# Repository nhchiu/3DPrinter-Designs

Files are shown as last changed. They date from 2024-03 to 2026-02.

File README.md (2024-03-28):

# 3D Printer Designs

Collection of miscellaneous parts and upgrades for 3D printers.

## Support

Making, testing, and sharing these designs take a lot of time and effort.

If you would like to support my work, the following platforms are available:




Thank you!

## License



Unless being specifically noted, the work in the repository is licensed under [CC BY-NC-SA 4.0](http://creativecommons.org/licenses/by-nc-sa/4.0/?ref=chooser-v1)

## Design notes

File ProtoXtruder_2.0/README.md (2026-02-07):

# ProtoXtruder 2.0

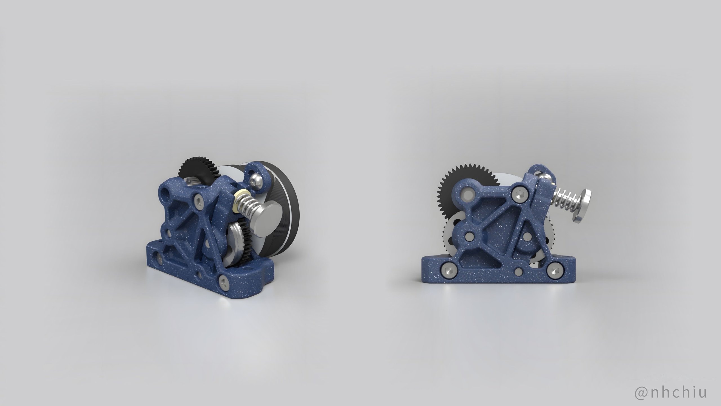
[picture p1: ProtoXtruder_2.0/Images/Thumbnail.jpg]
Thumbnail


This is the successor to [ProtoXtruder](https://www.printables.com/model/436425-protoxtruder).
With the new gears from the [HGX 2.0 Extruder](https://s.click.aliexpress.com/e/_Dmy9Crl) **(affiliate link)**,
the design becomes thinner and lighter while preserving the benefits of the larger gears.

Although it is named ProtoXtruder **2.0**, it's not a direct upgrade from the previous design.
There isn't much you can reuse in the BOM.

Refer to the drawing below for dimensions and compatibility with your printer.
The mounting holes are compatible with the [Sherpa Mini Extruder](https://github.com/Annex-Engineering/Sherpa_Mini-Extruder).

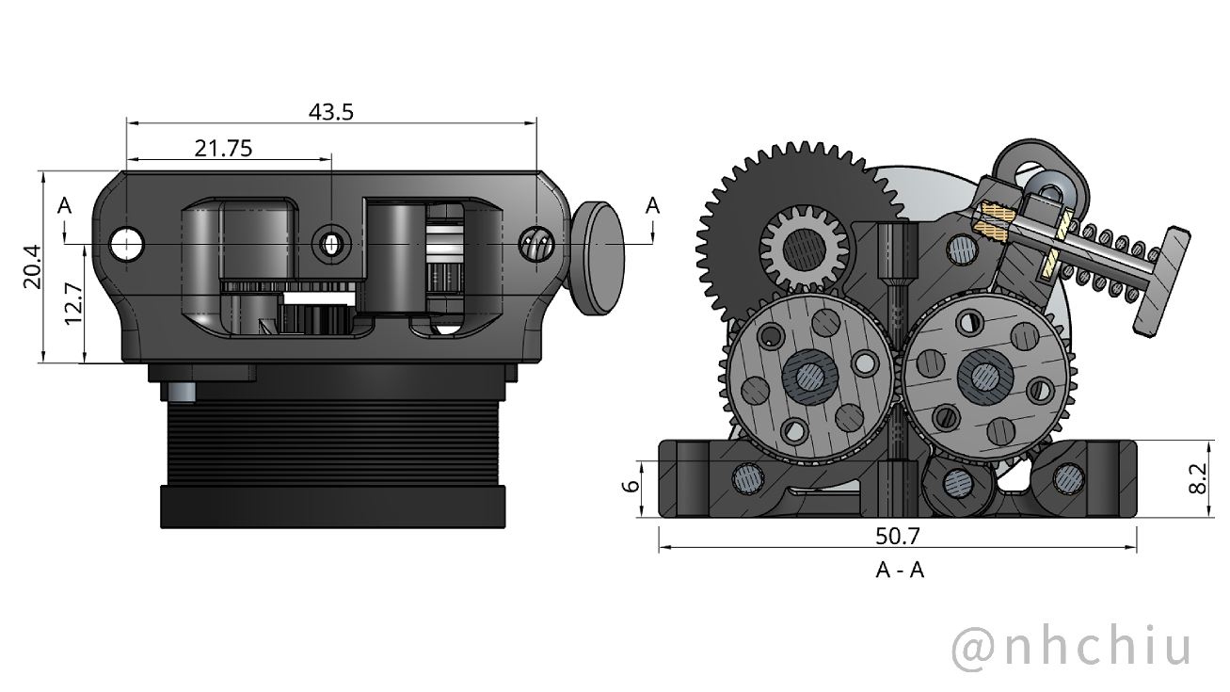
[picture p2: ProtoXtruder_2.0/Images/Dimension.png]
Dimension


If you'd like to support my work, the following platforms are available. Thank you!




> This page contains affiliate links. If you purchase products through these links, I may earn a small commission at no additional cost to you.
> This helps support the development and maintenance of my projects. Thank you for your support!

## Features

- High gear reduction ratios (44:10, 37:17).
- Large extrusion gears (18 mm diameter) providing a large filament contact area.
- Oblique/twirling hobbed teeth for improved filament grip and consistent flow.*
- Compact and lightweight. All printed parts can be produced in about one hour.
- Variants for different Bowden tube retainers.
- Low profile and low center of mass.
- Optional support for a toolhead filament sensor.

> [!NOTE]
> *: The effect of the oblique/twirling teeth still needs further testing.
>
> Below are pros and cons based on my experience and feedback regarding the [Vz-HextrudORT](https://github.com/VzBoT3D/Vz-HextrudORT):
>
> Pros:
>
> - It requires very little tension to provide a very good grip on the filament.
> - The inclined tooth profile causes less deviation in flow rate when it leaves tooth marks on the filament.
>
> Cons:
>
> - It introduces a twisting force on the filament under higher back pressure from the hotend.
>   This may cause issues when printing flexible materials or at high flow rates.
>
> I haven't observed issues with the HGX 2.0 gears so far, but your mileage may vary.

## Weight Comparison

This is a rough reference; the parts were not printed in identical materials or with identical print profiles.

The CNC Vz-HextrudORT I received is from early batches.
Later versions added more cutouts, so newer ones are likely lighter.

From left to right:

|  Extruder  | CNC<br />VzHextrudort | Sherpa mini | Hummingbird | ProtoXtruder | ProtoXtruder 2.0 | HGX 2.0 |
| :---: | :---: | :---: | :---: | :---: | :---: | :-----: |
| Weight (g) | 40.0 | 34.9 | 49.6 | 46.4 | 39.5 |  51.0 |

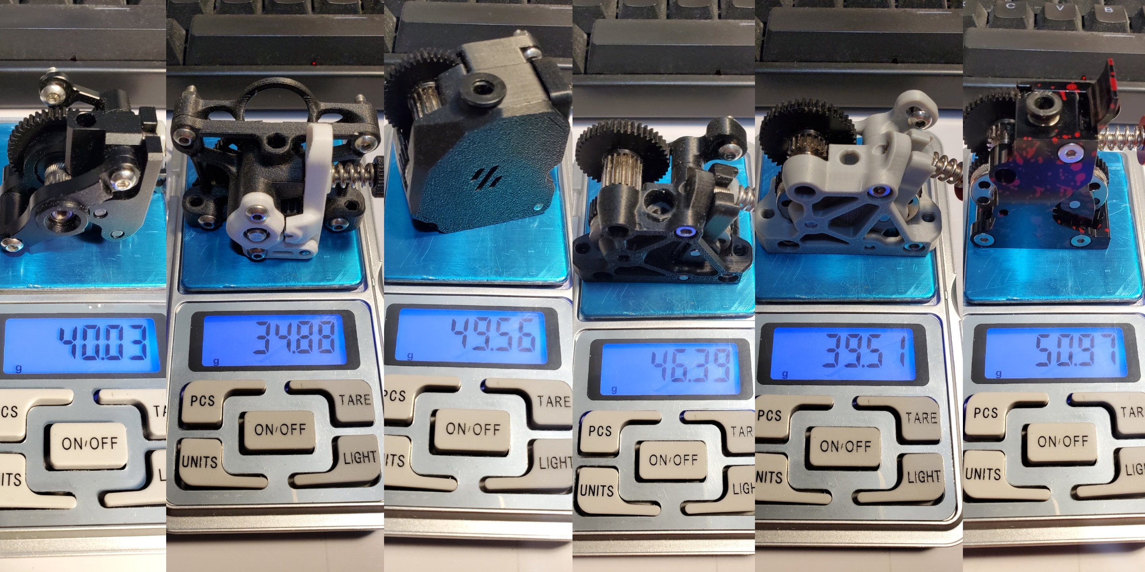
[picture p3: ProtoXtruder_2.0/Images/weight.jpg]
weight


## BOM

- Oblique Tooth HGX 2.0 Extruder Gear Kit ([this](https://s.click.aliexpress.com/e/_Dmy9Crl) or [this](https://s.click.aliexpress.com/e/_Dn3gb6n)) **(both are affiliate links)**. (I'm not certain what's included in the gear kit; I'll update this as I receive confirmation or feedback.)
  - MR63ZZ bearings × 6
  - 3 mm shaft (18 mm length) × 1 (16–18 mm may work)
  - 3 mm shaft (16 mm length) × 1 (14–16 mm may work)
  - Large extrusion gear (with oblique teeth) × 2
  - Reduction gear × 1
  - Thumb screw and tensioner spring
- Fasteners:
  - M3 × 8 mm BHCS × 1
  - M3 × 16 mm SHCS × 3
  - M3 × 20 mm SHCS × 1
  - Heat-set inserts (Voron size — M3 × D5 × H4) × 3
- NEMA14 36 mm round pancake motor with 10T gear (8T should be compatible)

## Print Settings

Use at least 3 perimeters and 40% infill. ABS or ASA recommended.

All STL files are oriented for printing; no supports required.

It will need *some* bridging.

## Assembly

1. Install M3 heat-set inserts.

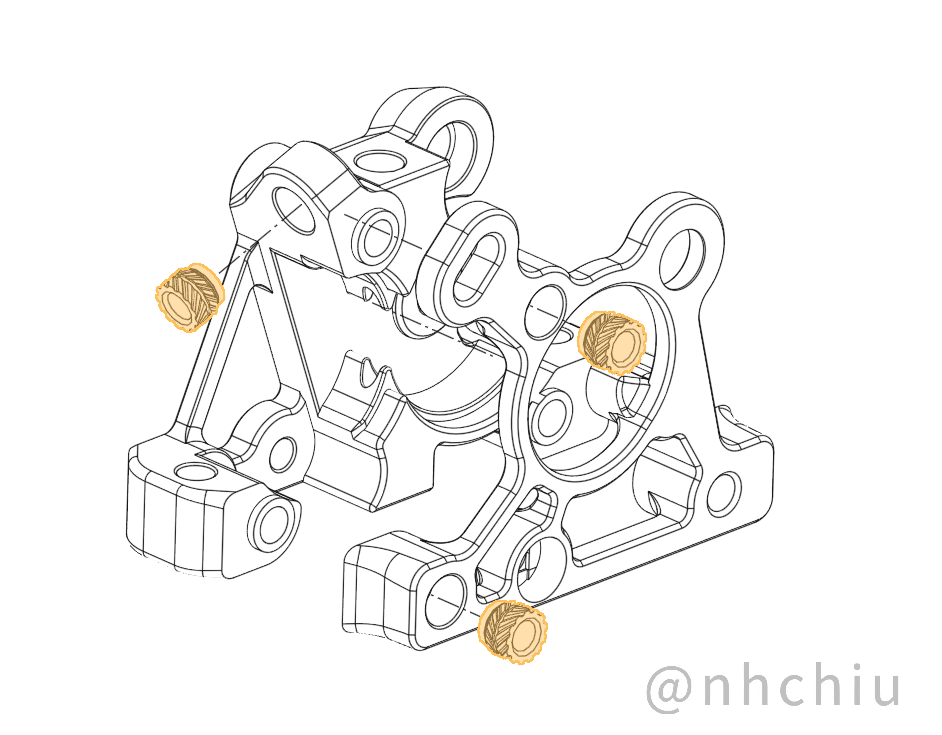
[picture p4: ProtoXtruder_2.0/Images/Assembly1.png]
Assembly1
   

2. Insert the MR63 bearings into the extrusion gears (two per gear).

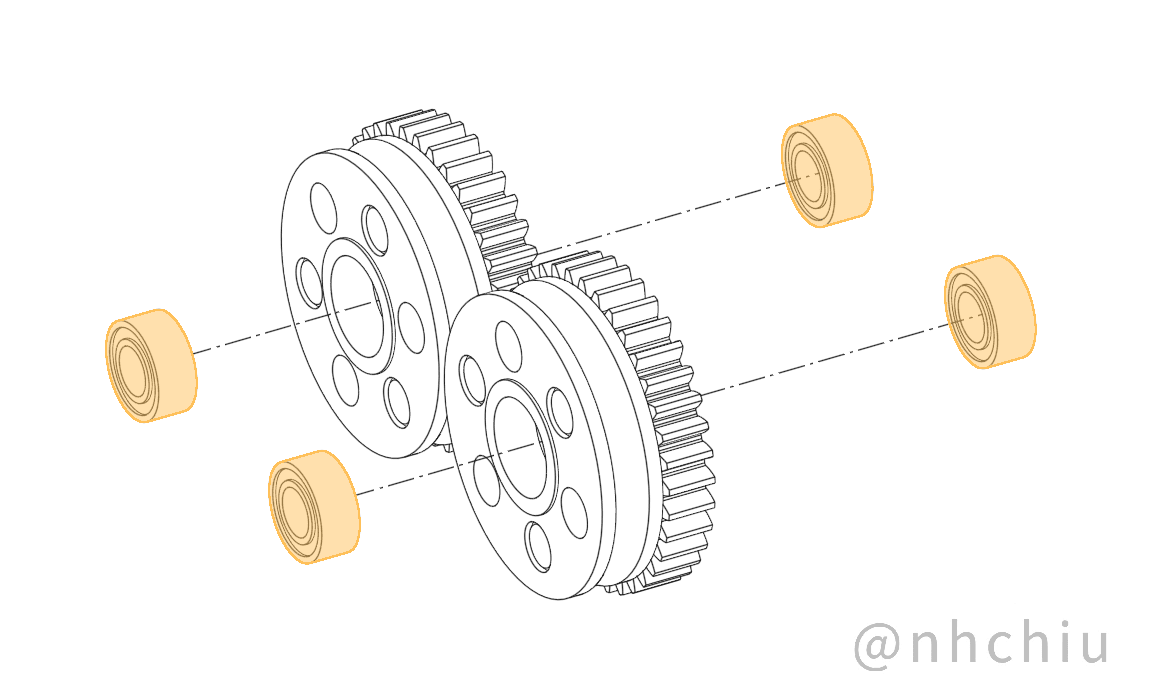
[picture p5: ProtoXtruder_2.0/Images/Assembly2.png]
Assembly2
   

3. Assemble the extruder using the fasteners.

   **Note: the M3 × 16 SHCS inserted from the motor side threads into plastic - do not overtighten.**
   **Tighten only until the screw head is flush with the printed part.**

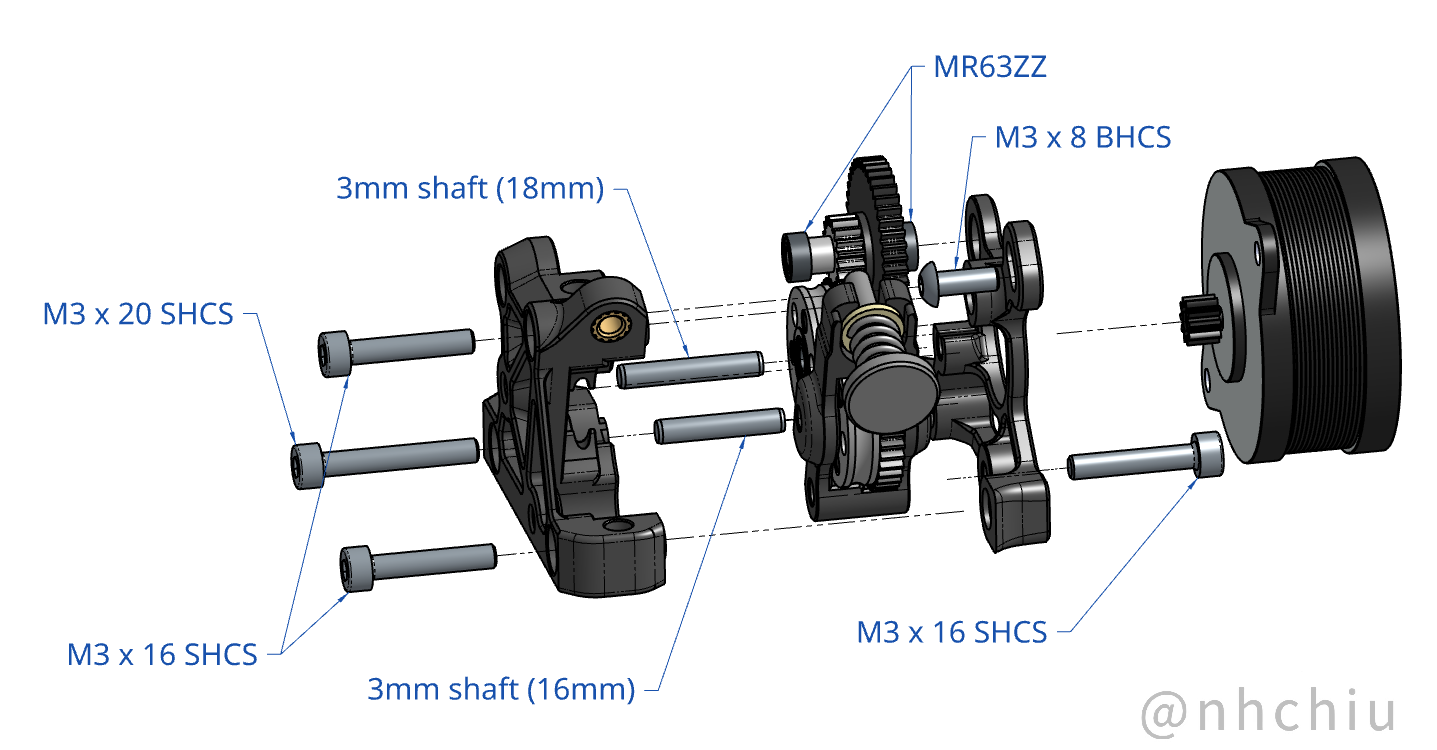
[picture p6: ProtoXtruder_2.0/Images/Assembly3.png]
Assembly3
   

4. (Optional) Add the Bowden tube retainer of your choice.

   **Remove the bottom half of the ECAS04 (the black plastic/rubber parts).**

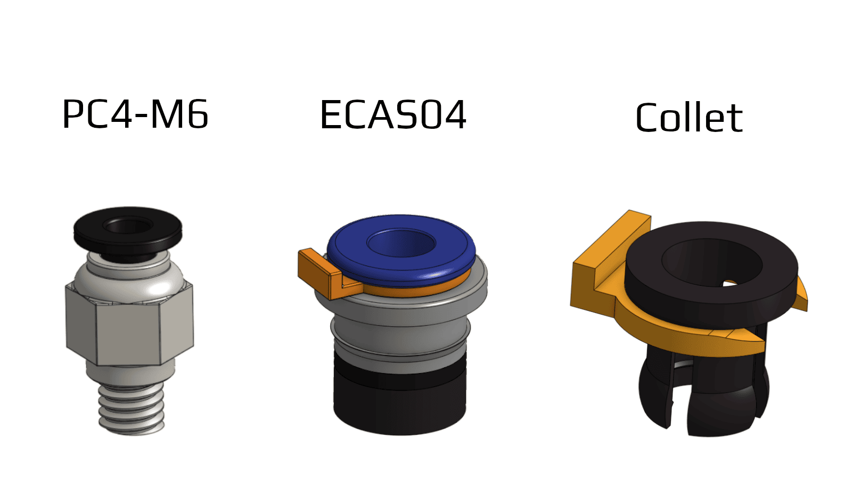
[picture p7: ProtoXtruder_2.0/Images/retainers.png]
retainers
   

## Toolhead Filament Sensor

Use in conjunction with this **Toolhead Filament Sensor for ProtoXtruder 2.0**

<iframe src="https://www.printables.com/embed/1589915" width="400" height="445" scrolling="no" frameborder="0"></iframe>

## Firmware Settings

For [Klipper firmware](https://www.klipper3d.org/):

```ini
[extruder]
rotation_distance: 53.494165  # Re-calibrate your own value
gear_ratio: 44:10, 37:17
```

**You might need to invert the `dir_pin` of the extruder.**

## Changelog

### 2026-02-08

- Add support for toolhead filament sensor

### 2024-04-19

- Update to match the pin length of the gear kit.

### 2024-03-28

- Initial release

## Special Thanks

Designing and testing an extruder takes a lot of time and many iterations.

Thanks to [Polymaker](https://polymaker.com/) for sponsoring the filament used to print many prototypes.

Also thanks to Haldis / HS3DPrinter for sending me an HGX 2.0 extruder so I could design with their new gears.
Their products are available on [their website](https://hs3dprinter.com/) and [AliExpress](https://s.click.aliexpress.com/e/_DchaZFt) **(affiliate link)**.

## Photo

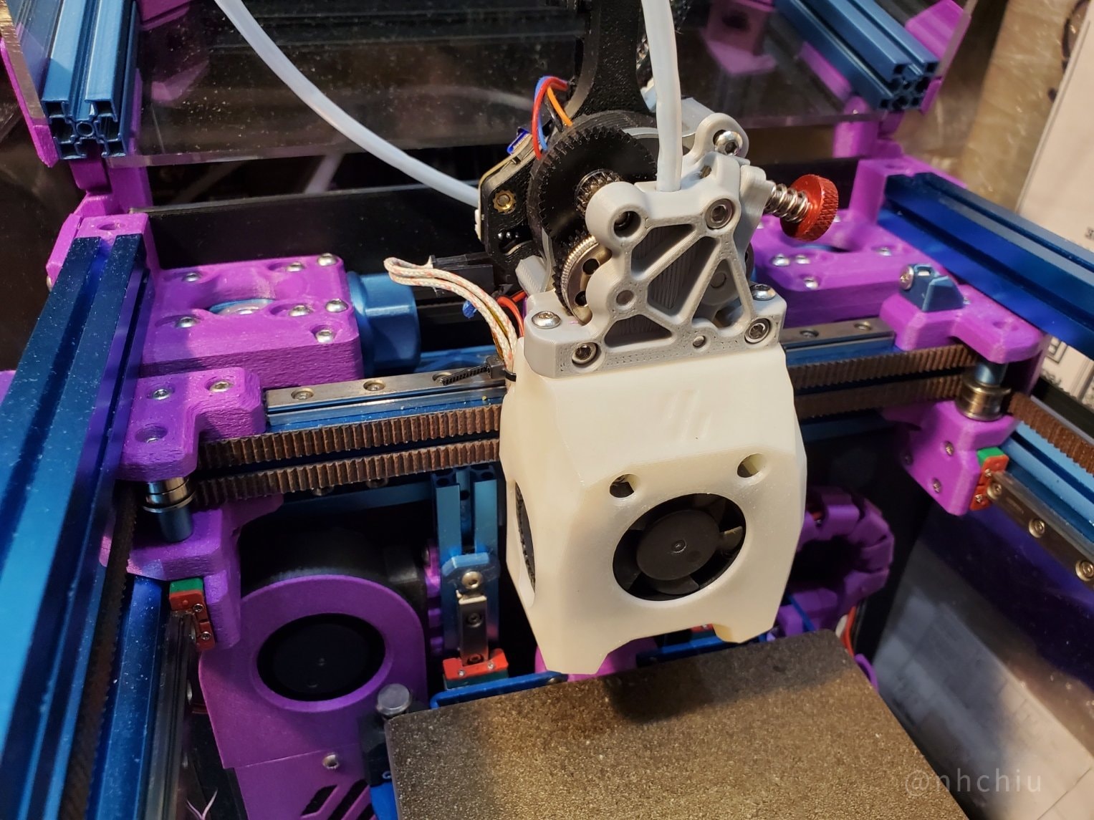
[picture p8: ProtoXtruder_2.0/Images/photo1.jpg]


## Credits

- The design is inspired by [Sherpa Mini Extruder](https://github.com/Annex-Engineering/Sherpa_Mini-Extruder) from [Annex Engineering](https://github.com/Annex-Engineering)

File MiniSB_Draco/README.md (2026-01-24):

# MiniSB Draco

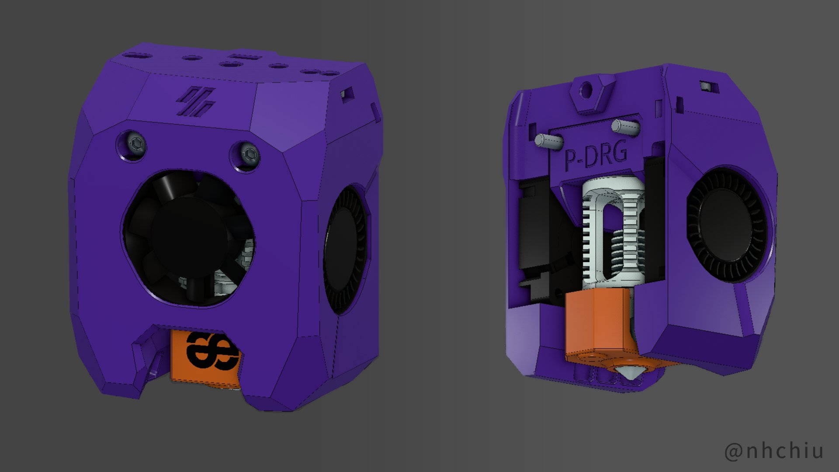
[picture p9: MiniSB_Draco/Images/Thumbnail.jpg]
Thumbnail


Yet another versatile toolhead design for Voron 0.2.

MiniSB Draco (for Dragon) is designed primarily to fix the miniSB's compatibility with the Phaetus Dragon hotend.

If you would like to support my work, the following platforms are available. Thank you!




> [!NOTE]
> \* Aliexpress links are *affiliate links*. If you purchase products through these links, I may earn a small commission at no additional cost to you.
> This helps support the development and maintenance of my projects. Thank you for your support!

## Features

- Interference occurs between 22 mm-diameter hotends and the X carriage on the miniSB. This toolhead was redesigned from scratch to avoid that. (NOTE: The print area is shifted 0.4 mm toward the front, so you may lose a bit of print area on V0. A slimmer X carriage is provided to compensate.)
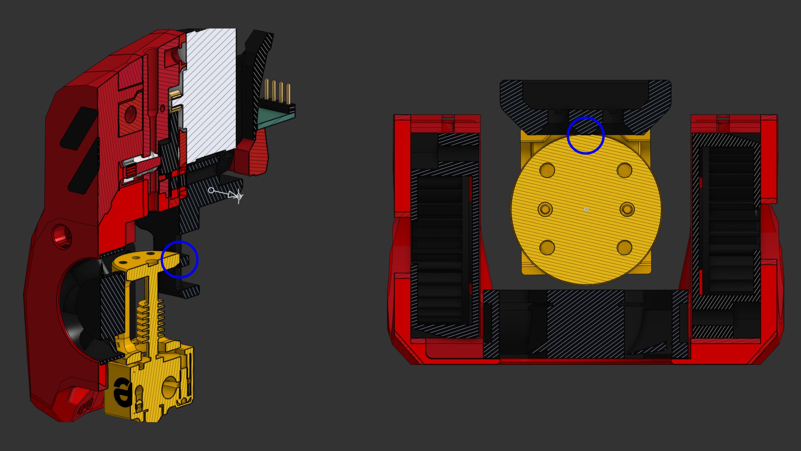
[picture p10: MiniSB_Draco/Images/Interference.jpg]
Interference
  
- Supports most common extruders; inspired by [Omniburner](https://www.printables.com/model/854317-omniburner-universial-mini-stealthburner-for-most).
- Supports the [Klicky probe](https://github.com/jlas1/Klicky-Probe/tree/main/Printers/Voron/v0) or [ZeroClick](https://github.com/zruncho3d/ZeroClick).
- Redesigned part-cooling fan duct; it may provide slightly better part-cooling performance. (Left side is the stock miniSB.)
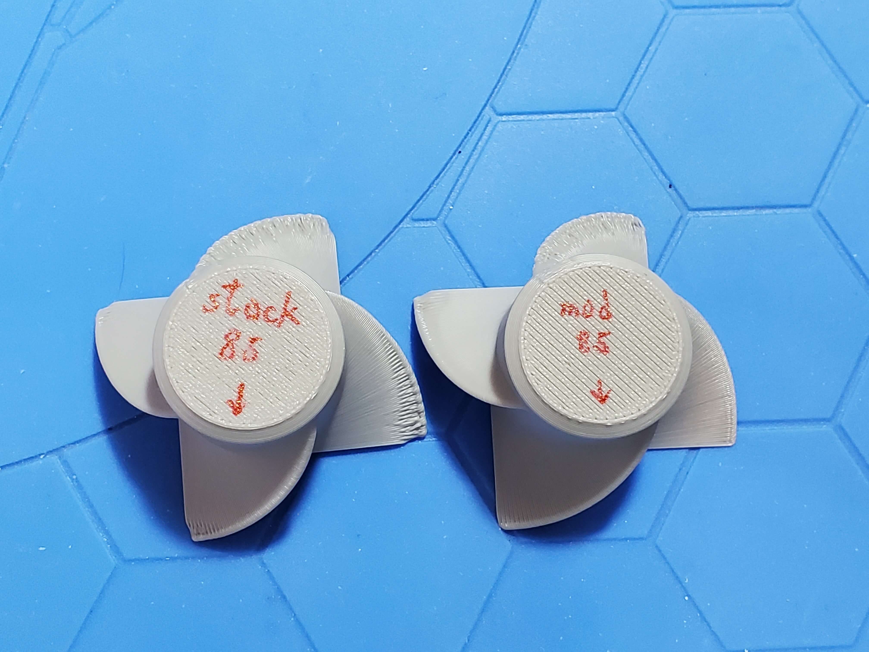
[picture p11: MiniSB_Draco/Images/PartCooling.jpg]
Part Cooling Test
  

## BOM

- 3010 blower fans for part cooling x 2
- 3010 axial fan for hotend cooling
- Fasteners:
  - **M3 hex nuts** x 3 (2 for Sherpa mini / Orbiter V2 mount, 1 for X carriage mount)
  - **M3x8mm BHCS** x 2 (VzHextrudort / LGX Light)
  - **M3x35mm BHCS** x 2 (X carriage mount)
  - **M3x20mm BHCS** x 1 (X carriage mount)
  - Fasteners for your hotend

## Supported Hardware

Choose a supported extruder and hotend listed below and print the corresponding STL files.

### Extruder

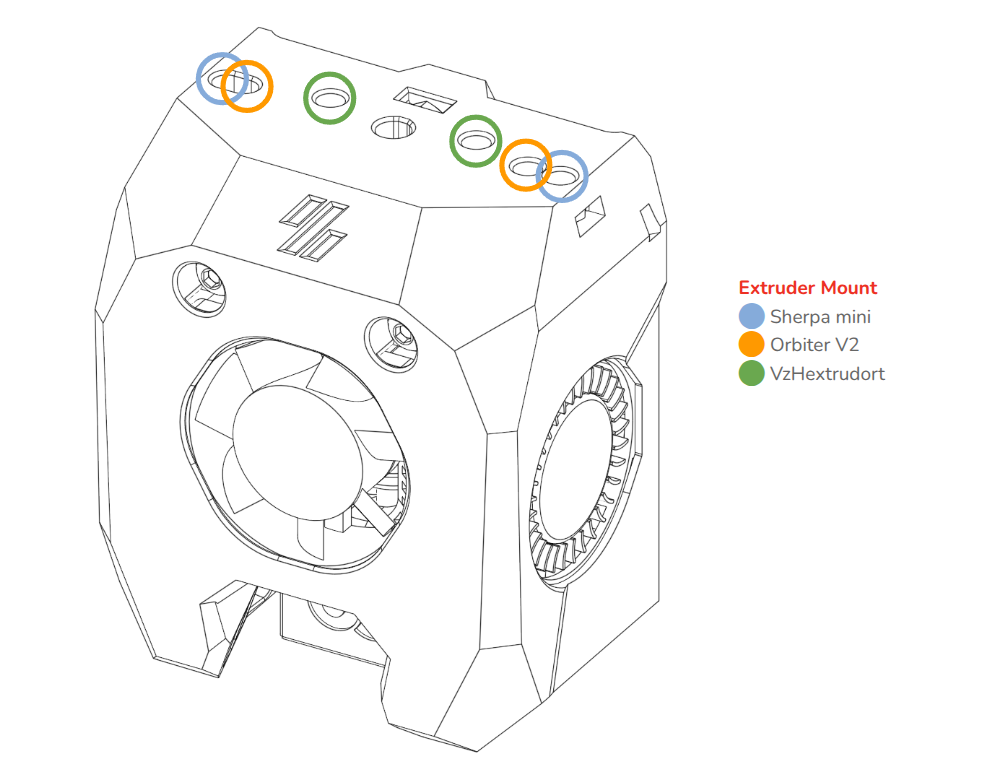
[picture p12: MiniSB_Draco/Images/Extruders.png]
extruder


There are 3 main types of supported extruders:

| Extruder | Alternatives |
| --- | --- |
| [Sherpa Mini](https://github.com/Annex-Engineering/Sherpa_Mini-Extruder) | [ProtoXtruder](https://www.printables.com/model/436425-protoxtruder) / [ProtoXtruder 2.0](https://www.printables.com/model/822947-protoxtruder-20) / [StealthProtoXtruder 2.0](https://www.printables.com/model/1372682-stealthprotoxtruder-20) |
| [Orbiter V2.0](https://orbiterprojects.com/orbiter-v2-0/) | [Orbiter V2.5](https://www.orbiterprojects.com/orbiter-v2-5/) / [Galileo 2 (G2SA)](https://github.com/JaredC01/Galileo2) |
| [Vz-Hextrudort](https://github.com/VzBoT3D/Vz-HextrudORT) | [LGX Lite](https://www.bondtech.se/product/lgx-lite-large-gears-extruder/) / [Hummingbird](https://www.printables.com/model/367706-hummingbird-extruder) |

### Hotend

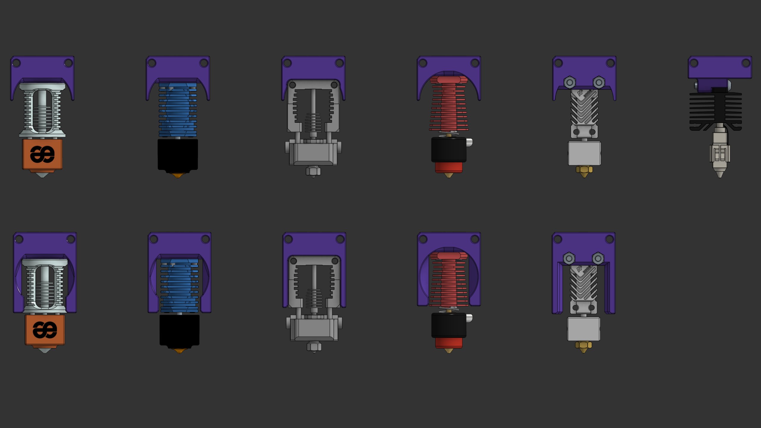
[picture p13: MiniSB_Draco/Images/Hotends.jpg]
hotend


| Hotend | Alternatives | Fasteners |
| --- | --- | --- |
| [Phaetus Dragon](https://www.phaetus.com/products/dragon-hotend-st) | [TZ-V6-2.0 \*](https://s.click.aliexpress.com/e/_c4XmgSCF) | **M2.5x8mm BHCS/SHCS** x 4 |
| [Phaetus Dragonfly BMO](https://www.phaetus.com/products/dragonfly-hotend-bmo) | | **M2.5x8mm BHCS/SHCS** x 4 |
| [Slice Engineering Mosquito](https://www.sliceengineering.com/products/the-mosquito-hotend) | [Mellow NF-Crazy SF](https://3dmellow.com/products/nf-crazy-v1-hotend) | **M2.5x8mm BHCS/SHCS** x 2 |
| [E3D Revo Voron](https://e3d-online.com/products/revo-voron-coldside-kits) | | **M3x8mm BHCS** x 4 |
| [Mellow NF-Zone-V6 \*](https://s.click.aliexpress.com/e/_c4D5KePZ) | | **M3x16mm BHCS** x 2, M3 Hex nuts x 2 |
| [Bambu Hotend - X1C](https://asia.store.bambulab.com/products/bambu-hotend-x1c) | [Phaetus Conch Hotend - X1/P1](https://www.phaetus.com/products/conch-hotend%E2%84%A2-x1-p1-series) | **M3x16mm BHCS** x 2, Heat set inserts (**M3 x D5 x H4**) x 2 |

## Print Settings

Use at least 3 perimeters and 40% infill. ABS or ASA are recommended.

All STL files are oriented for printing. No supports required.

## Assembly

1. Prep for X carriage.

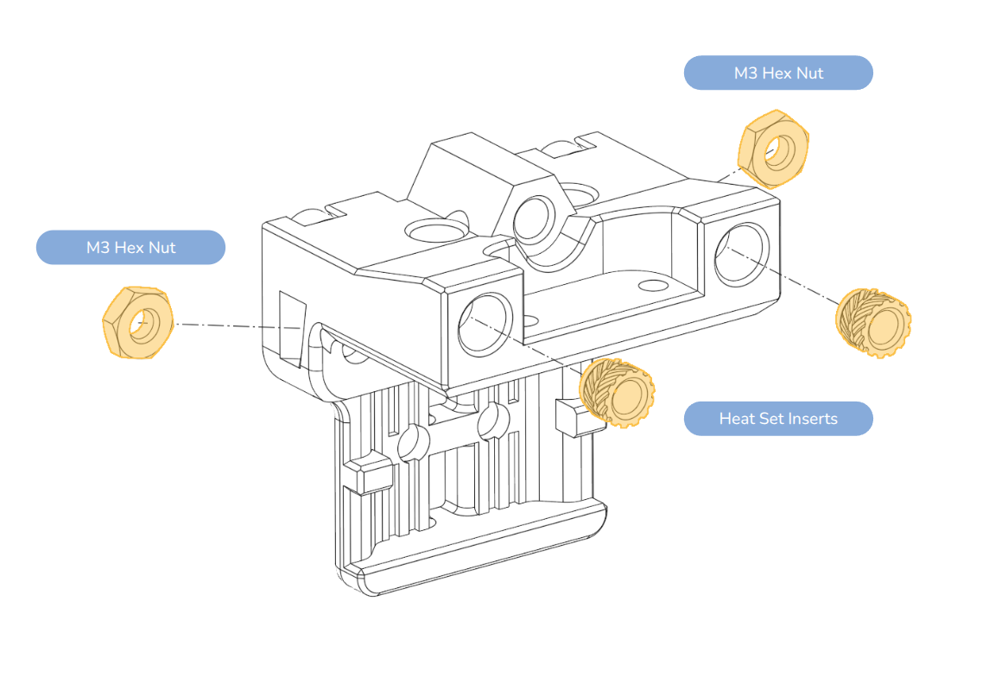
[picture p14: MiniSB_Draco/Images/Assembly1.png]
Assembly1
   
2. Screw the reinforcement screws into the plastic. (Optional)

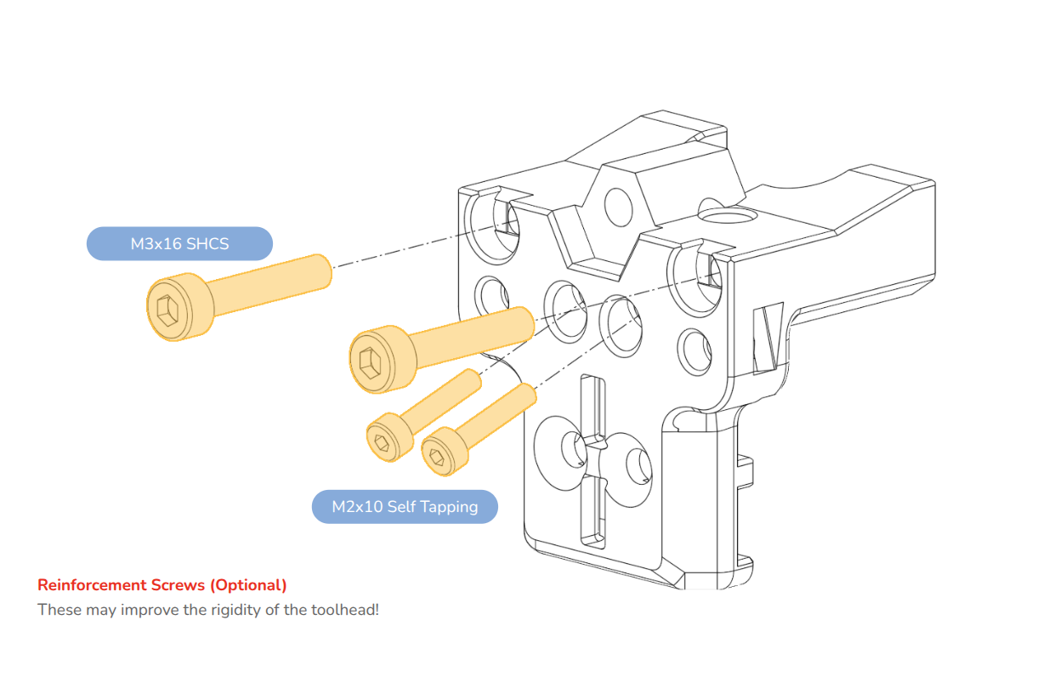
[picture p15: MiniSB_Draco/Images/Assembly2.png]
Assembly2
   
3. If you are using ZeroClick or the Klicky probe, follow their instructions to prepare the probe mount.

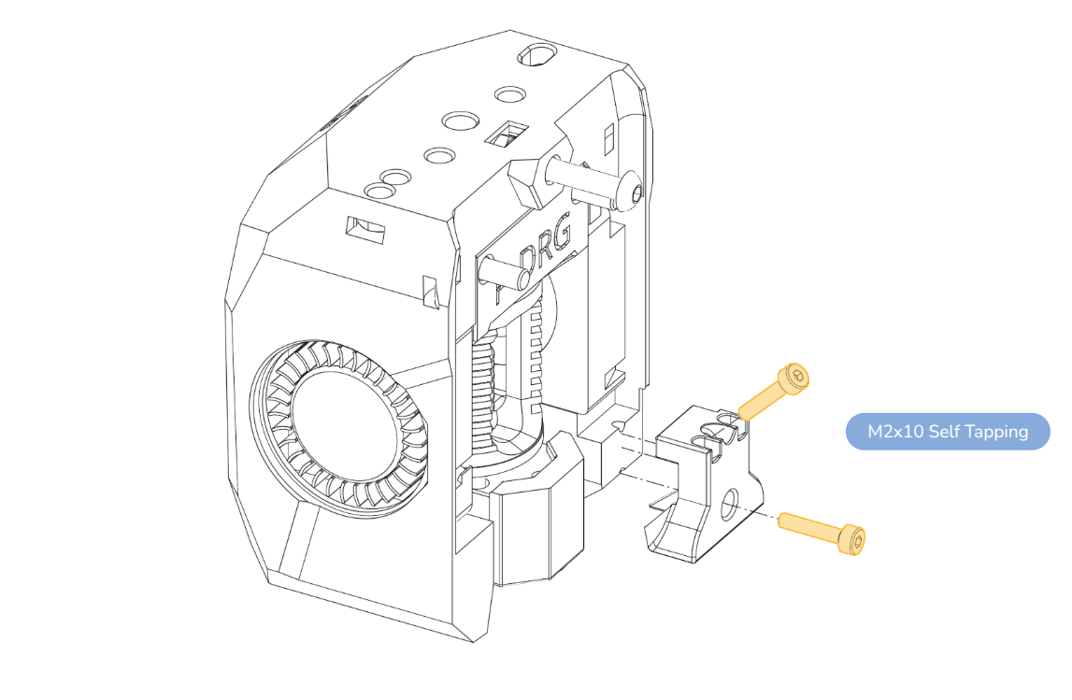
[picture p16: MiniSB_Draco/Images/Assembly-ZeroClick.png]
Assembly-ZeroClick
   
4. Mount the toolhead to the X carriage.

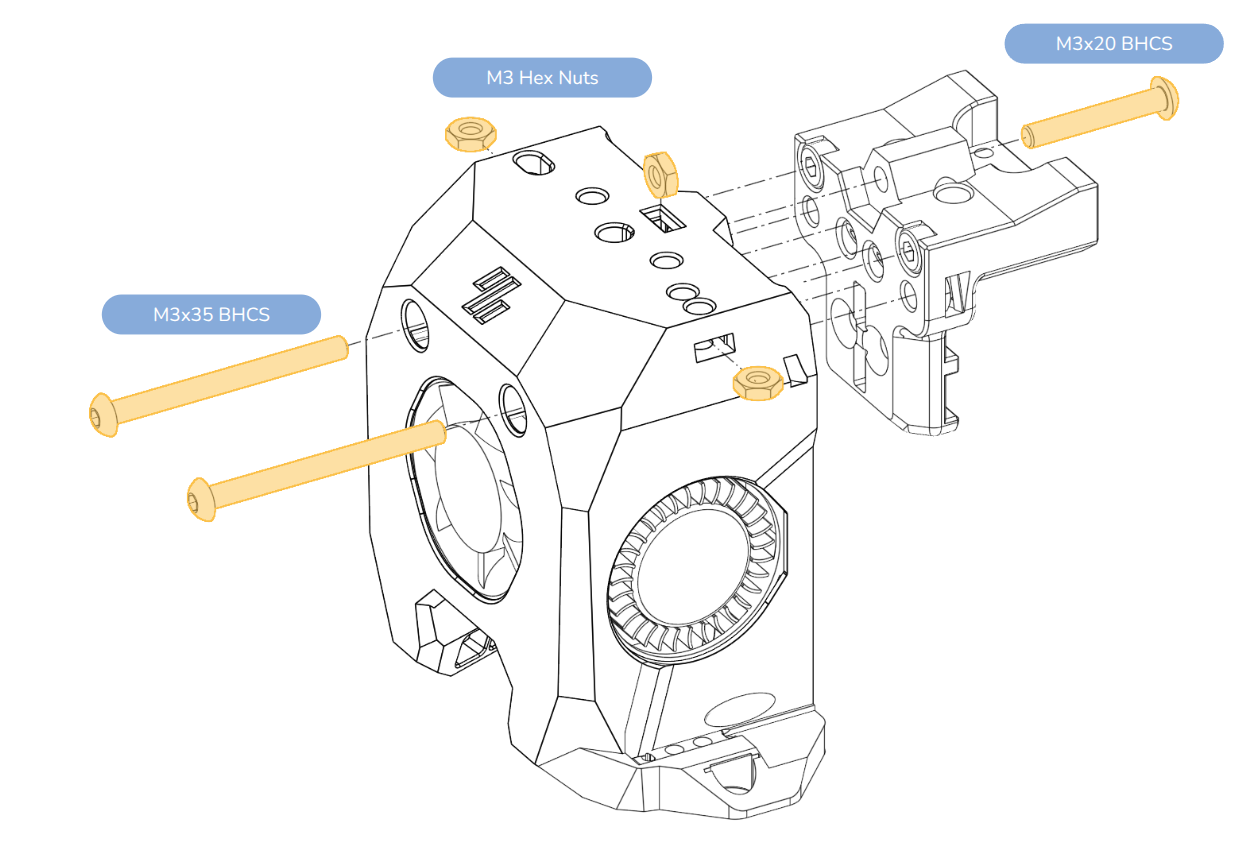
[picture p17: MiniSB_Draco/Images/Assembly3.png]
Assembly3
   

## Changelog

### 2026-01-24

- Initial release

## Photo

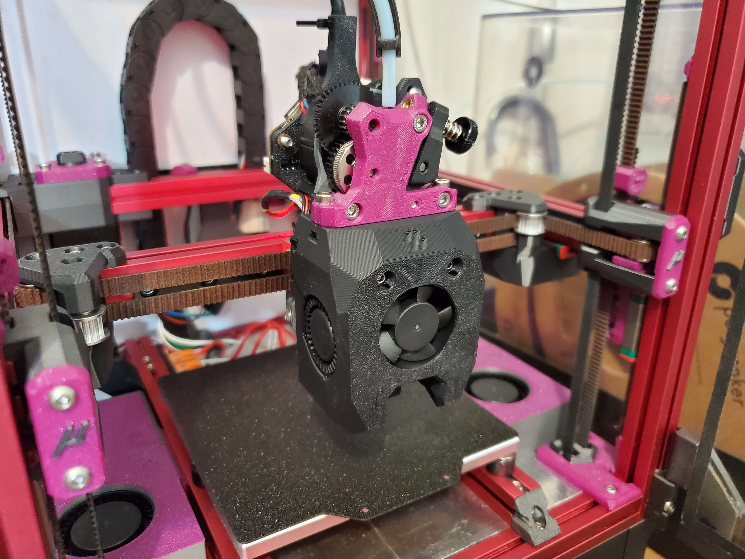
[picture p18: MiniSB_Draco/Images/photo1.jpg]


## Credits

- The stock toolhead design: [miniStealthBurner](https://github.com/VoronDesign/Voron-0/tree/Voron0.2r1/STLs/Toolheads/Mini_Stealthburner).
- [Omniburner](https://www.printables.com/model/854317-omniburner-universial-mini-stealthburner-for-most).

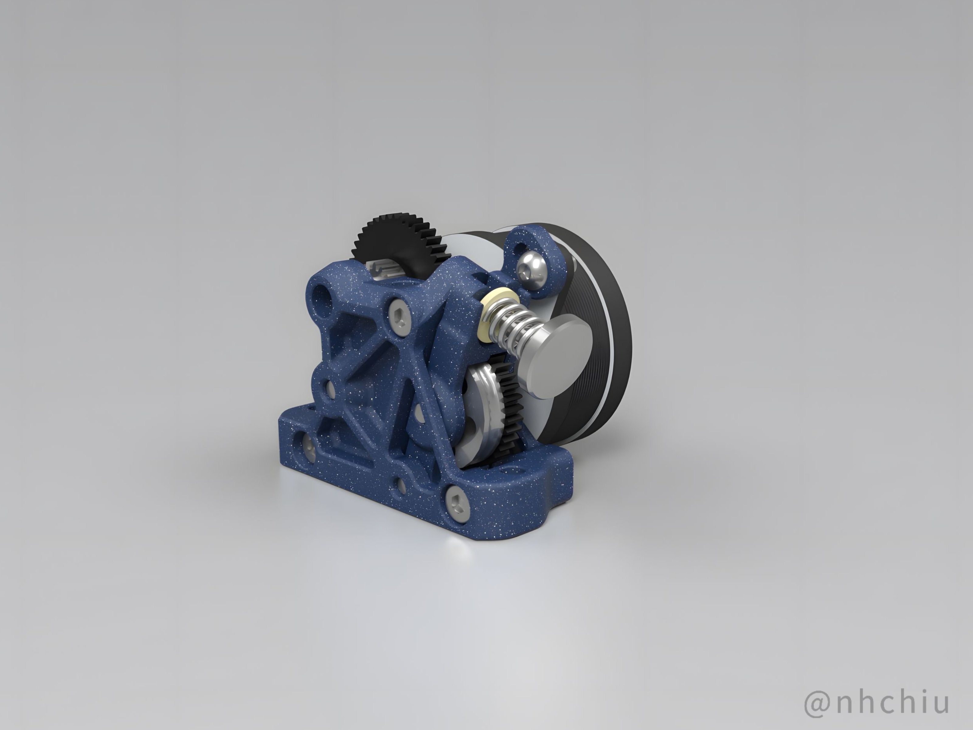
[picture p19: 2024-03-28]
ProtoXtruder_2.0/Images/Render1.jpg

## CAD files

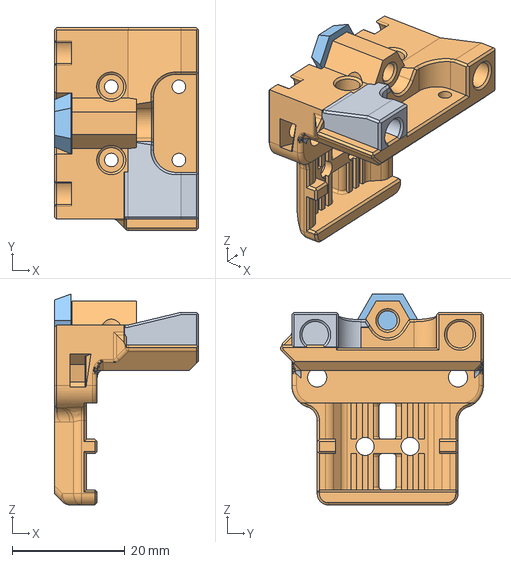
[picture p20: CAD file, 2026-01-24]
MiniSB_Draco/CAD/V0 X Carriage Slim.step
25.6 x 36.0 x 37.5 mm

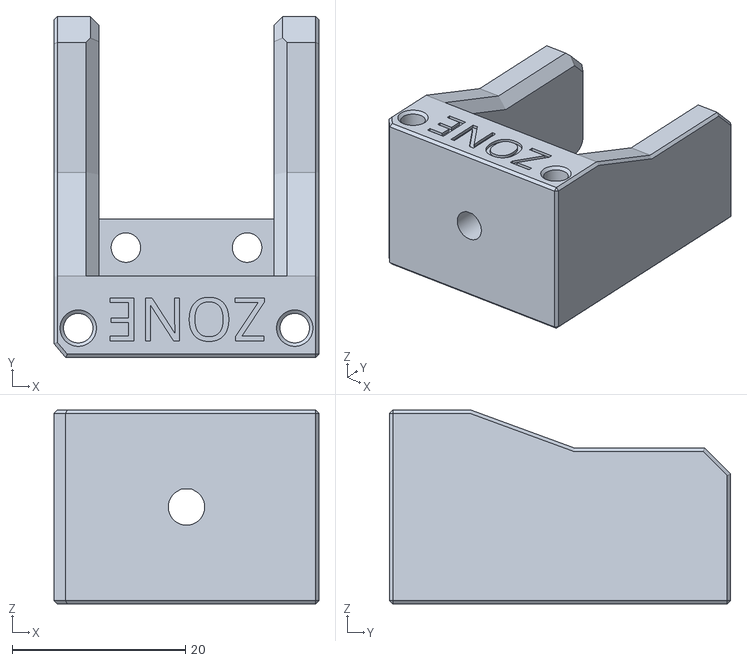
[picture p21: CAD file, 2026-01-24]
MiniSB_Draco/STLs/Hotend Mounts/Fan Saver/Hotend Mount ZoneV6 FS.stl
30.6 x 39.4 x 22.4

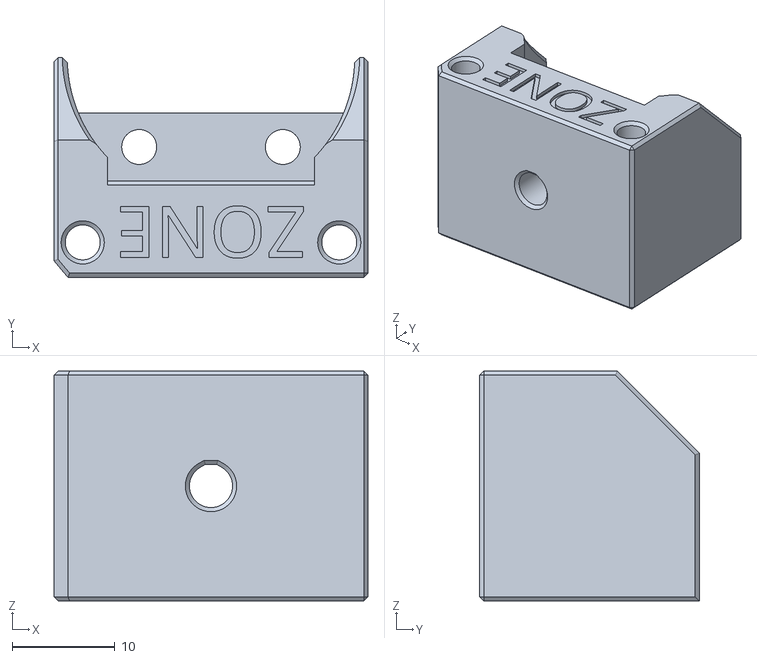
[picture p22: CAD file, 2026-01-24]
MiniSB_Draco/STLs/Hotend Mounts/Standard/Hotend Mount ZoneV6.stl
30.6 x 21.4 x 22.4

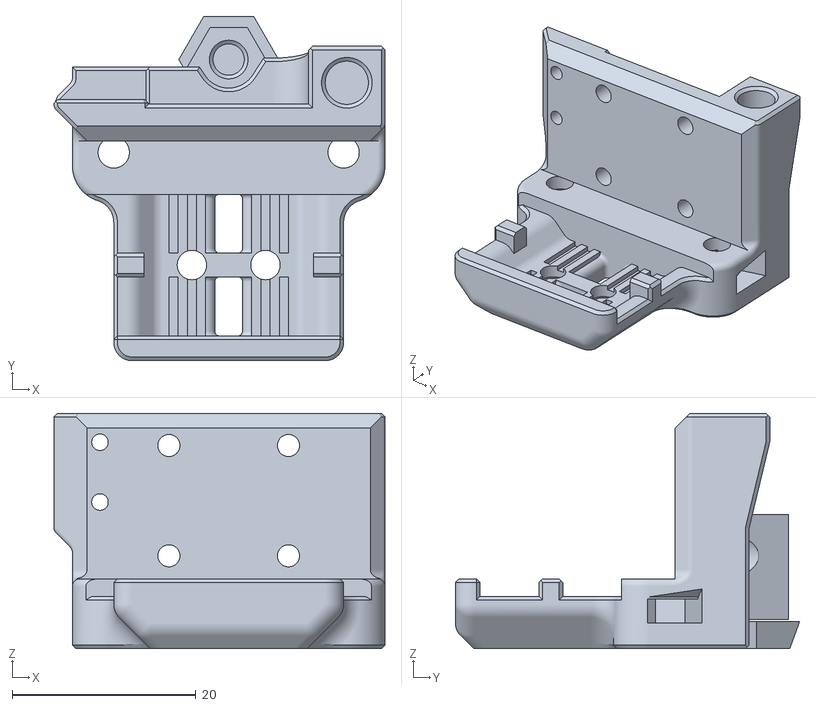
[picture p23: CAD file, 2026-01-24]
MiniSB_Draco/STLs/X Xarriage Slim/V0 X Carriage - Endstop.stl
36.0 x 37.5 x 25.6

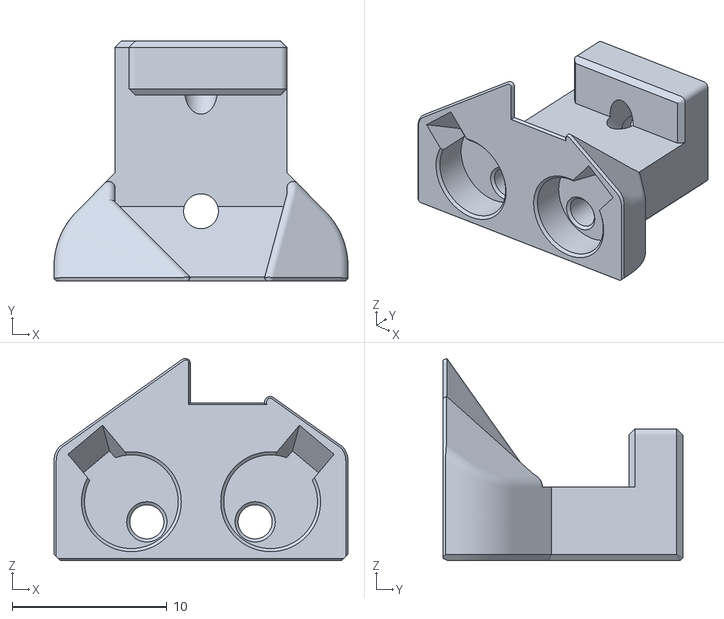
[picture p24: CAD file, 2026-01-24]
MiniSB_Draco/STLs/Zeroclick Mount.stl
19.0 x 15.5 x 13.1

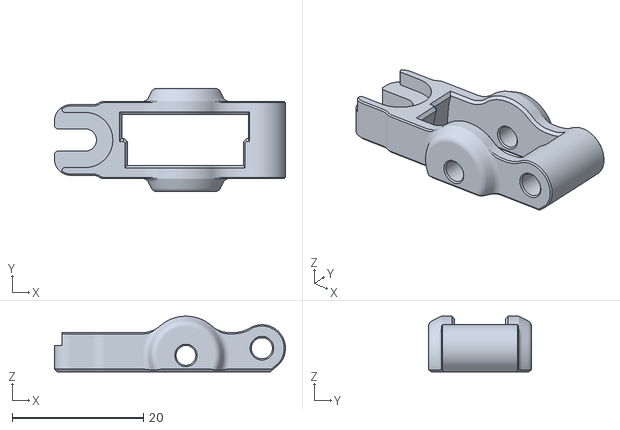
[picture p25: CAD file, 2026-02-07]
ProtoXtruder_2.0/STLs/Idler_arm.stl
35.3 x 15.8 x 8.50

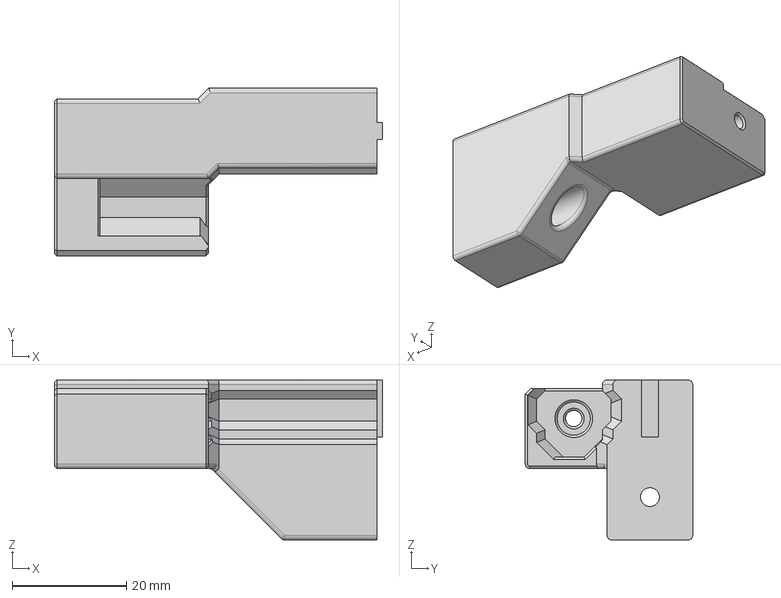
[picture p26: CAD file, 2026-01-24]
MiniSB_Draco/CAD/ZeroClick Center Dock - V0.step
57.4 x 29.3 x 28.0 mm

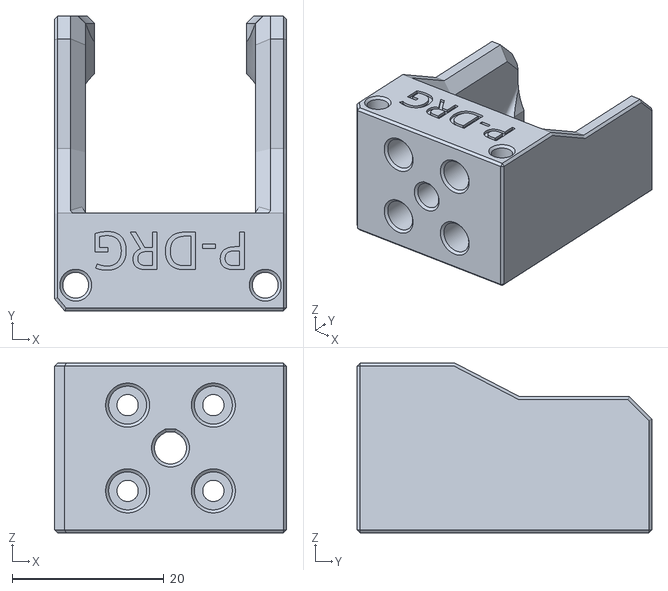
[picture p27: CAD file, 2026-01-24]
MiniSB_Draco/STLs/Hotend Mounts/Fan Saver/Hotend Mount Dragon FS.stl
30.6 x 38.9 x 22.4

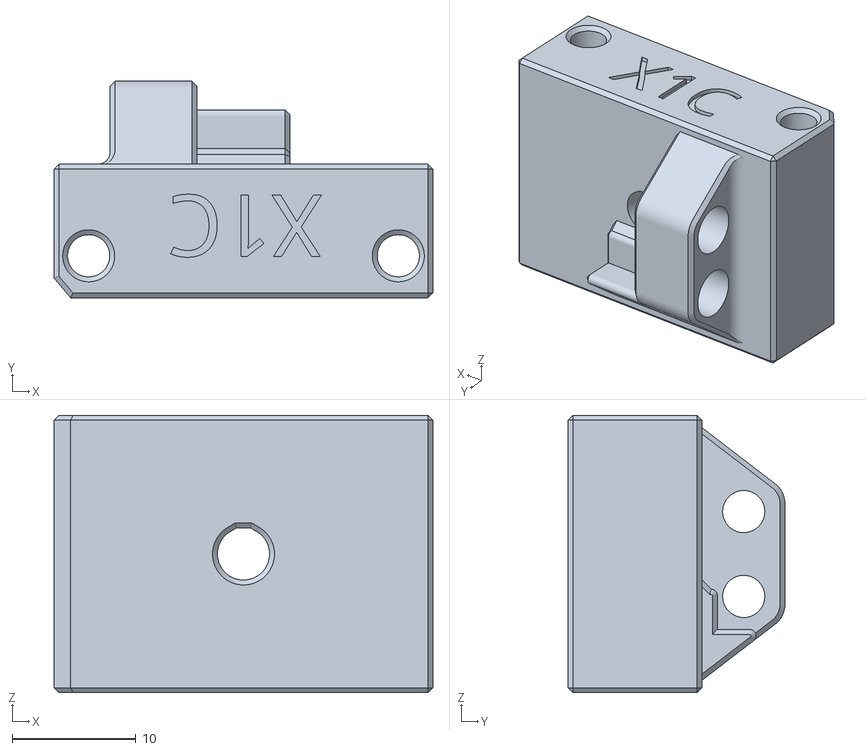
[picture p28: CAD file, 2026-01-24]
MiniSB_Draco/STLs/Hotend Mounts/Standard/Hotend Mount Bambu.stl
30.6 x 17.5 x 22.4

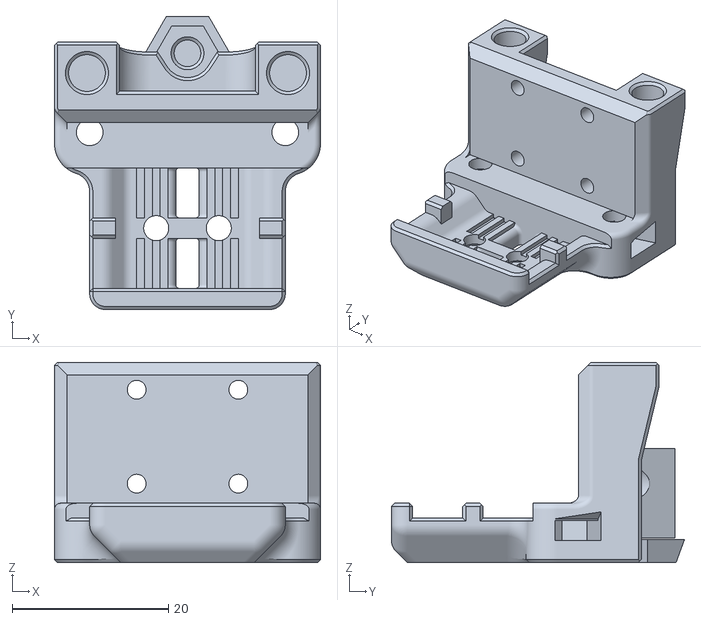
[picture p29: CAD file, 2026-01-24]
MiniSB_Draco/STLs/X Xarriage Slim/V0 X Carriage.stl
34.0 x 37.5 x 25.6

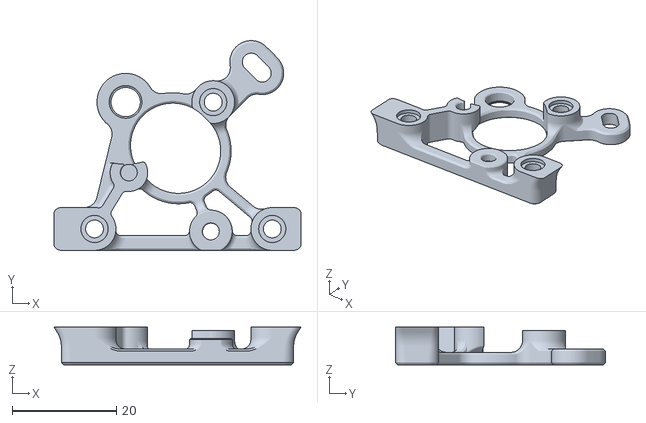
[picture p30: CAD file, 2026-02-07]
ProtoXtruder_2.0/STLs/Back.stl
47.3 x 40.2 x 7.20

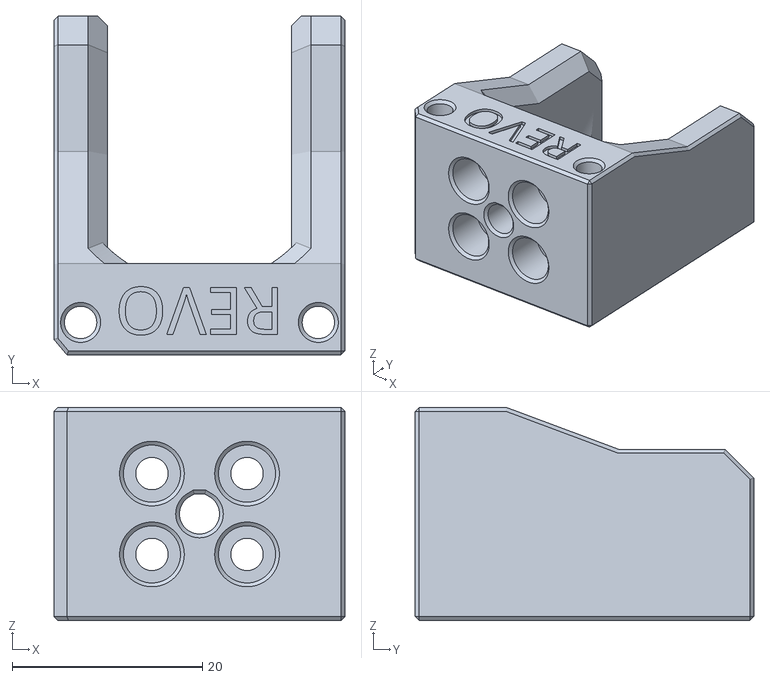
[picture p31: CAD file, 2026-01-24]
MiniSB_Draco/STLs/Hotend Mounts/Fan Saver/Hotend Mount Revo FS.stl
30.6 x 35.6 x 22.4

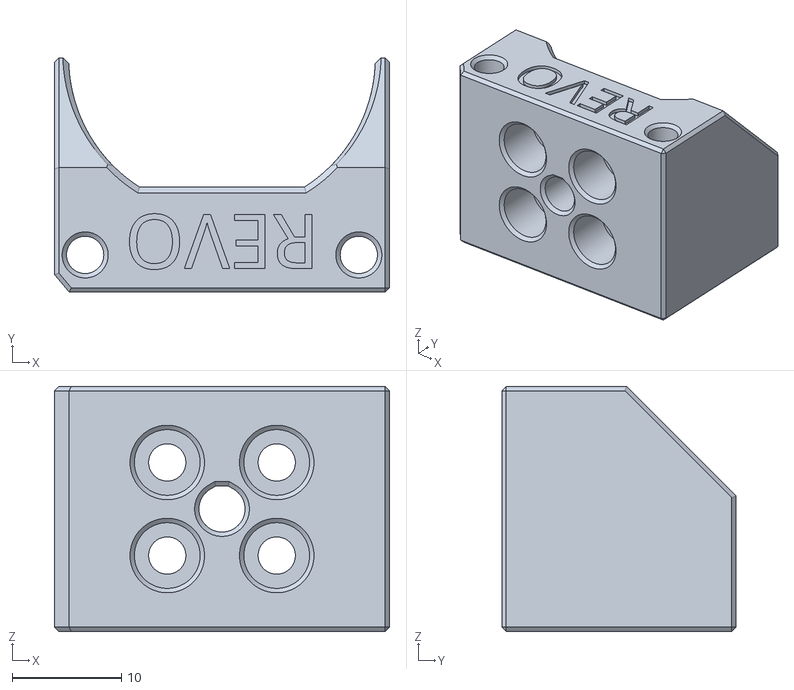
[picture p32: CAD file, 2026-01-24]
MiniSB_Draco/STLs/Hotend Mounts/Standard/Hotend Mount Revo.stl
30.6 x 21.4 x 22.4

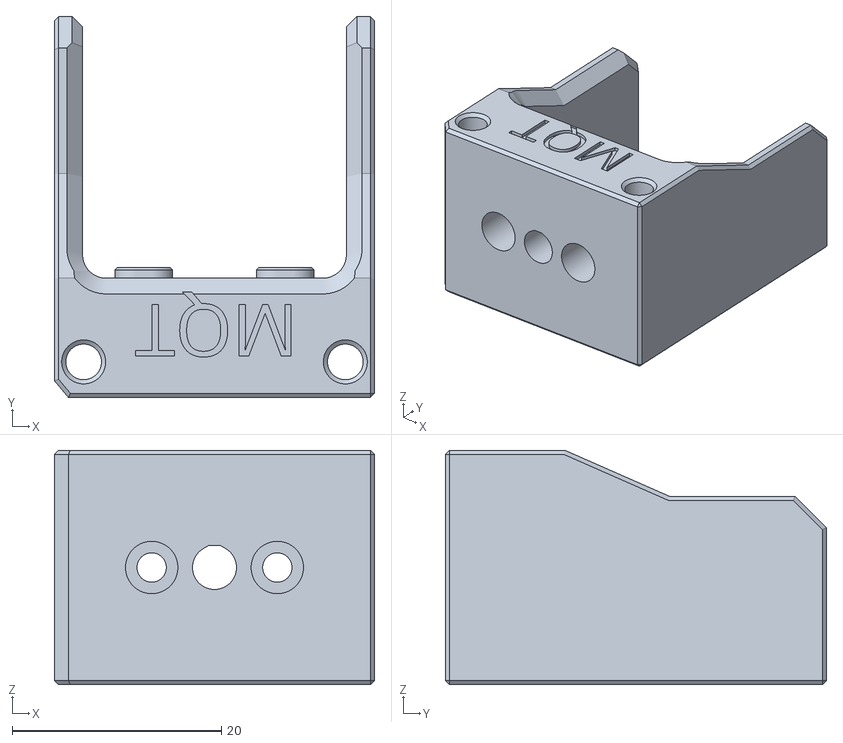
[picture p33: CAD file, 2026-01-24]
MiniSB_Draco/STLs/Hotend Mounts/Fan Saver/Hotend Mount Mosquito FS.stl
30.6 x 36.4 x 22.4

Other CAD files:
MiniSB_Draco/STLs/Hotend Mounts/Fan Saver/Hotend Mount BMO FS.stl
MiniSB_Draco/STLs/Hotend Mounts/Standard/Hotend Mount Mosquito.stl
MiniSB_Draco/STLs/Hotend Mounts/Standard/Hotend Mount Dragon.stl
MiniSB_Draco/STLs/Hotend Mounts/Standard/Hotend Mount BMO.stl
MiniSB_Draco/STLs/ZeroClick Center Dock - V0.stl

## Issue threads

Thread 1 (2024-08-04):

[ProtoXtruder 2.0] Missing tensioning spring/knob?

benbender, 2024-08-04:
Hey,

first and foremost: Thanks for your amazing work! <3

I'm just looking at the ProtoXtruder 2.0 and I'm missing the tensioning spring and knob. Are they included in the gear kit or are they missing from the BOM?

nhchiu, 2024-08-04:
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

Hi! Thanks for asking.
It should be included in the gear kit. (You can double check with the seller)
I forgot to have it listed in the BOM. I'll fix it later. Thanks for catching that!

Closed 2024-08-04.

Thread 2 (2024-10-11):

Improvement possible on collet version

MartijnGevaert, 2024-10-11:
Hi, really like the ProtoXtruder and Protoxtruder v2!

One thing I did notice is that the collet version of Protoxtruder v1 (did not check v2), does not allow for the PTFE tube to be as easily deeply and easily inserted as on a sherpa mini mod I run.
I have 6 sherpa mini's and all accept the tube easily. For my 2 protoxtruders the tube can't go in far enough.
I understand from the CAD this is partially intended, but I believe the sherpa mini collet system is more reliable and leads to less gaps in the smooth filament path.

Looking at the CAD, there does seem to be a difference.
I believe Protoxtruder would be improved by copying over the geometry used by sherpa mini.

Currently not being able to fully seat the tube makes filament loading more difficult as it often get's caught when exiting the tube and entering the extruder.

https://github.com/Annex-Engineering/Annex-Engineering_User_Mods/tree/main/Extruders/Sherpa_Mini/Extruder_Mods/Ryan_G-Idler_Filament_Sensor_and_Collet

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

nhchiu, 2024-10-11:
Awesome! Thanks for your suggestion.
I'll try to add this feature to the extruders.

MartijnGevaert, 2024-10-11:
Cool!

Moving the collet "geometry" up by 1 mm will also give it more clearance to the tensioning screw on the right. Currently the collet can't be completely pressed in which likely also doesn't help with tube insertion. The small clips are usually used to force the collet in this "closed" position.
I don't think this increase by 1mm would impact performance.
It might also not be necessary after the sherpa mini system is used.
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

Let me know if I can help by printing out a test version. I do only have HGX-Lite V1 sets at the moment.

nhchiu, 2024-10-12:
OK! Got it! I don't use collets myself so didn't notice these details.
Thanks again for the feedback.
I'll keep you updated.

nhchiu, 2024-10-13:
@MartijnGevaert Hello! I've made the corresponding tweaks, also I made the cutout the same dimension as  the Sherpa mini mod.
If you don't mind doing a test print, here's the updated file. Technically you only need the new front part but I included all 3 parts just in case.
Thank you!

[ProtoXtruder.zip](https://github.com/user-attachments/files/17356875/ProtoXtruder.zip)

MartijnGevaert, 2024-10-15:
> @MartijnGevaert Hello! I've made the corresponding tweaks, also I made the cutout the same dimension as the Sherpa mini mod. If you don't mind doing a test print, here's the updated file. Technically you only need the new front part but I included all 3 parts just in case. Thank you!
>
> [ProtoXtruder.zip](https://github.com/user-attachments/files/17356875/ProtoXtruder.zip)

Sorry I didn't see your message earlier, I'll try it out tomorrow.

MartijnGevaert, 2024-10-16:
I printed it out, it's great! Tube inserts firmly and filament goes in smoothly, all the way to the gears now, no hickups or anything. Tube also doesn't come out and plenty of clearance for the collet clip.
Collet is the option included in the hgx-lite gear kit, so I think a lot of people will be able to enjoy the benefits of these changes!
Thanks a bunch!

nhchiu, 2024-10-17:
> I printed it out, it's great! Tube smoothly all the way and filament goes in smoothly all the way to the gears now, no hickups or anything. Tube also doesn't come out now and plenty of clearance for the collet clip which locks it in place. Collet is the option included in the hgx-lite gear kit, so I think a lot of people will be able to enjoy the benefits of these changes! Thanks a bunch!

Great! Thanks for doing the test.
I'll update the parts in the repo.

MartijnGevaert, 2024-10-17:
One thing I did think of is a small chamfer around the piece that sticks out that the collet goes into. This would improve printability by reducing the angle of the overhang. Otherwise perfect.

nhchiu, 2024-10-18:
> One thing I did think of is a small chamfer around the piece that sticks out that the collet goes into. This would improve printability by reducing the angle of the overhang. Otherwise perfect. ![image](https://private-user-images.githubusercontent.com/41551215/377605166-47a88313-c8a9-46ed-9ae5-5b25a4483ee7.png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)

OK. Got you.

MartijnGevaert, 2024-10-18:
Please don't put too much time into this, it's really a minor thing.

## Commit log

2024-03-28 Add ProtoXtruder
    [Back.stl, Idler_arm.stl]
2024-04-18 [PX 2.0] Update to match the pin length of the gear kit
    [Back.stl, Idler_arm.stl]
2024-08-04 [PX 2.0] Add the thumb screw included in the gear kit to BOM
    Fixes [ProtoXtruder 2.0] Missing tensioning spring/knob? #1
2026-01-24 Add MiniSB Draco toolhead design and associated files
    - Introduced new images for assembly and part cooling.
    - Added README.md detailing features, BOM, supported hardware, print settings, assembly instructions, and credits.
    - Included STL files for various hotend mounts, cowling designs, and X carriage slim versions.
    - Ensured compatibility with Phaetus Dragon hotend and other common extruders.
    [Hotend Mount BMO FS.stl, Hotend Mount BMO.stl, Hotend Mount Bambu.stl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]
2026-01-24 [ImgBot] Optimize images
    *Total -- 2,225.48kb -> 1,973.51kb (11.32%)
    /MiniSB_Draco/Images/Extruders.png -- 187.14kb -> 140.09kb (25.14%)
    /MiniSB_Draco/Images/Assembly-ZeroClick.png -- 188.21kb -> 141.33kb (24.91%)
    /MiniSB_Draco/Images/Assembly2.png -- 177.80kb -> 135.43kb (23.83%)
    /MiniSB_Draco/Images/Assembly3.png -- 278.13kb -> 215.73kb (22.43%)
    /MiniSB_Draco/Images/Assembly1.png -- 192.64kb -> 161.95kb (15.93%)
    /MiniSB_Draco/Images/Interference.jpg -- 350.68kb -> 337.41kb (3.78%)
    /MiniSB_Draco/Images/Hotends.jpg -- 155.16kb -> 150.51kb (3%)
    /MiniSB_Draco/Images/Thumbnail.jpg -- 110.96kb -> 108.41kb (2.29%)
    /ProtoXtruder_2.0/Images/retainers.png -- 64.78kb -> 63.90kb (1.37%)
    /ProtoXtruder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
2026-02-07 Add support for toolhead filament sensor
    [Back.stl, Idler_arm.stl]
